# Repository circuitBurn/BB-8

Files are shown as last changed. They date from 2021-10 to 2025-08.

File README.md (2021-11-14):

## PCB files and Arduino sketches for FrSky SBUS control of Joe's Drive

### Required Libraries
* https://www.arduino.cc/reference/en/libraries/dfrobotdfplayermini/
* https://www.arduino.cc/reference/en/libraries/bolder-flight-systems-sbus/
* https://www.arduino.cc/reference/en/libraries/adafruit-bno055/
* https://github.com/adafruit/Adafruit-PWM-Servo-Driver-Library
* https://www.arduino.cc/reference/en/libraries/bts7960/

### TODO
* Calibration functions
* General cleanup

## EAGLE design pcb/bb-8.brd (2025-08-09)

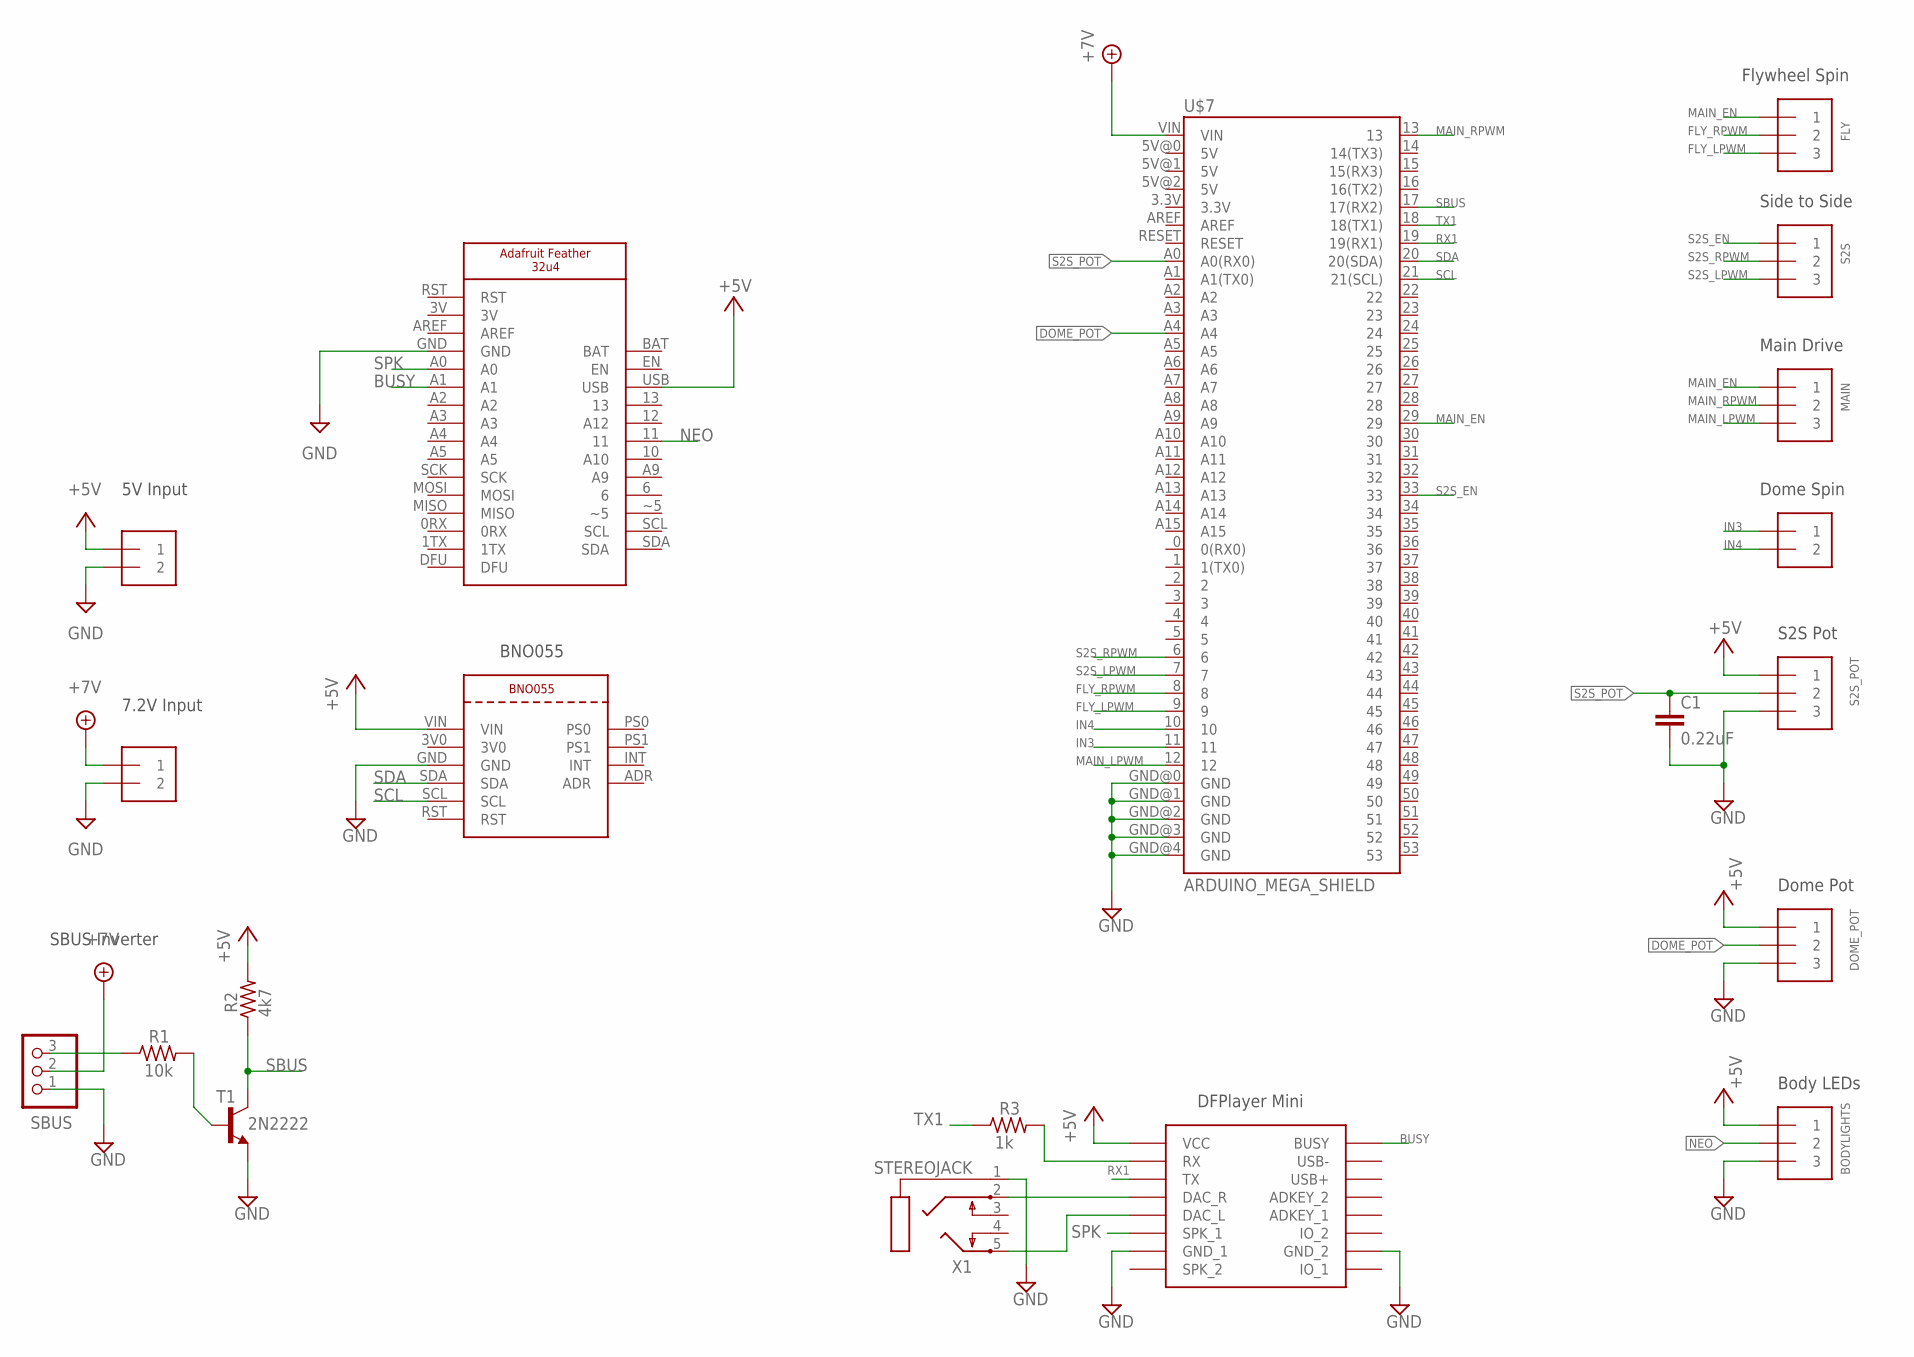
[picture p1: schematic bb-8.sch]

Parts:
5V, 7V2: 1X2-3.5MM
BODYLIGHTS: SCREW_TERMINAL_3_PIN
C1: 0.22uF; C050-024X044
DOME: 1X2-3.5MM
DOME_POT: SCREW_TERMINAL_3_PIN
FLY: SCREW_TERMINAL_3_PIN
MAIN: SCREW_TERMINAL_3_PIN
R1: 10k; 0204/7
R2: 4k7; 0204/7
R3: 1k; 0204/7
S2S, S2S_POT: SCREW_TERMINAL_3_PIN
SBUS: PINHD-1X3; 1X03
T1: 2N2222; TO92-EBC-OVAL
U$1: DFPLAYER
U$2: ADAFRUIT_BNO055
U$3: ADAFRUIT_FEATHER_32U4
U$7: ARDUINO_MEGA_SHIELD
X1: STEREOJACK; STX3100

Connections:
+5V: 5V.1, BODYLIGHTS.1, DOME_POT.1, R2.2, S2S_POT.1, U$1.VCC, U$2.VIN, U$3.USB
+7V: 7V2.1, SBUS.2, U$7.VIN
BUSY: U$1.BUSY, U$3.A1
DAC_R: U$1.DAC_R, X1.2
DOME_POT: DOME_POT.2, U$7.A4
FLY_LPWM: FLY.3, U$7.9
FLY_RPWM: FLY.2, U$7.8
GND: 5V.2, 7V2.2, BODYLIGHTS.3, C1.2, DOME_POT.3, S2S_POT.3, SBUS.1, T1.E, U$1.GND_1, U$1.GND_2, U$2.GND, U$3.GND, U$7.GND@0 (GND), U$7.GND@1 (GND), U$7.GND@2 (GND), U$7.GND@3 (GND), U$7.GND@4 (GND), X1.1
IN3: DOME.1, U$7.11
IN4: DOME.2, U$7.10
MAIN_EN: FLY.1, MAIN.1, U$7.29
MAIN_LPWM: MAIN.3, U$7.12
MAIN_RPWM: MAIN.2, U$7.13
unnamed: R1.2, T1.B
unnamed: R3.2, U$1.RX
unnamed: R1.1, SBUS.3
unnamed: U$1.DAC_L, X1.5
NEO: BODYLIGHTS.2, U$3.11
RX1: U$1.TX, U$7.19 (19(RX1))
S2S_EN: S2S.1, U$7.33
S2S_LPWM: S2S.3, U$7.7
S2S_POT: C1.1, S2S_POT.2, U$7.A0 (A0(RX0))
S2S_RPWM: S2S.2, U$7.6
SBUS: R2.1, T1.C, U$7.17 (17(RX2))
SCL: U$2.SCL, U$7.21 (21(SCL))
SDA: U$2.SDA, U$7.20 (20(SDA))
SPK: U$1.SPK1 (SPK_1), U$3.A0
TX1: R3.1, U$7.18 (18(TX1))

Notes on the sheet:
5V Input
7.2V Input
DFPlayer Mini
S2S Pot
Dome Pot
Flywheel Spin
Side to Side
Main Drive
Dome Spin
SBUS Inverter
BNO055
Body LEDs

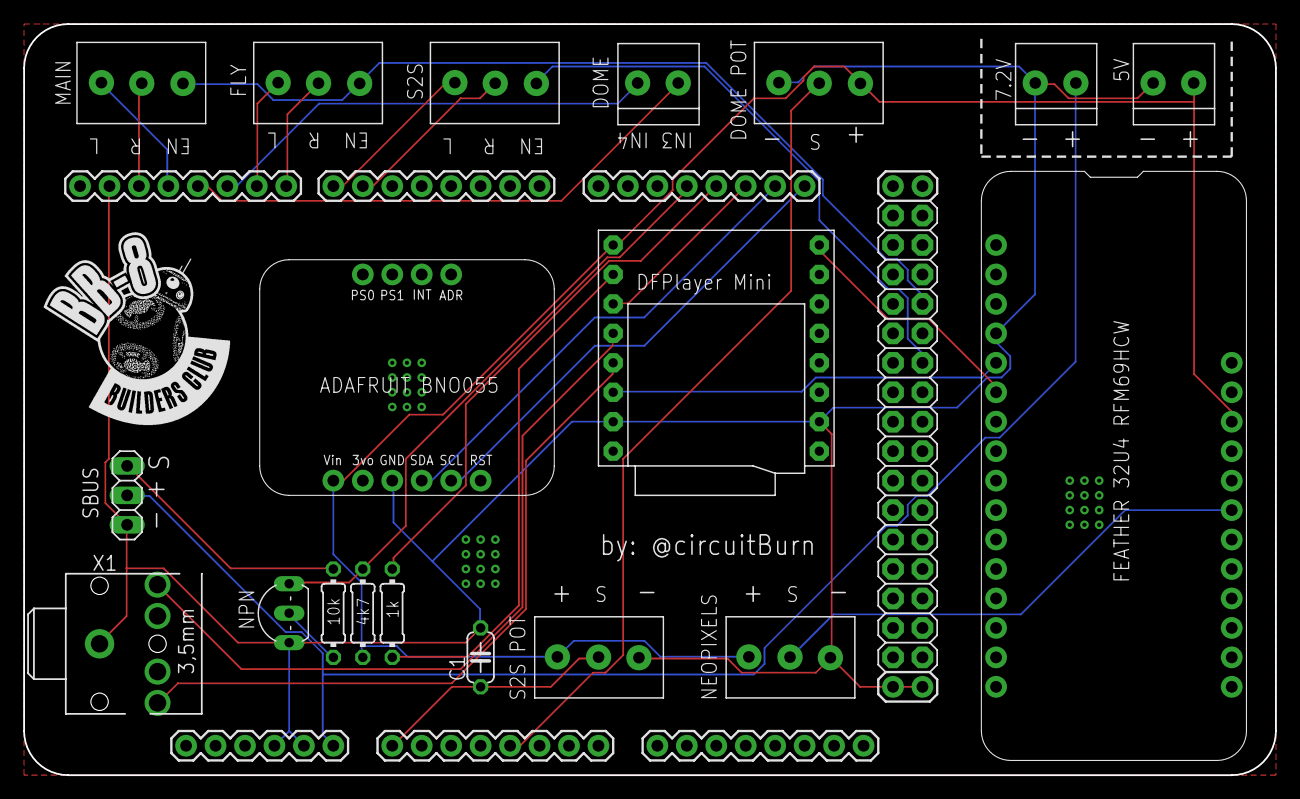
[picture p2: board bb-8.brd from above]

Board: 2 copper layers, 108.0 x 64.8 mm, 20 parts (0 on the bottom side), 28 nets.

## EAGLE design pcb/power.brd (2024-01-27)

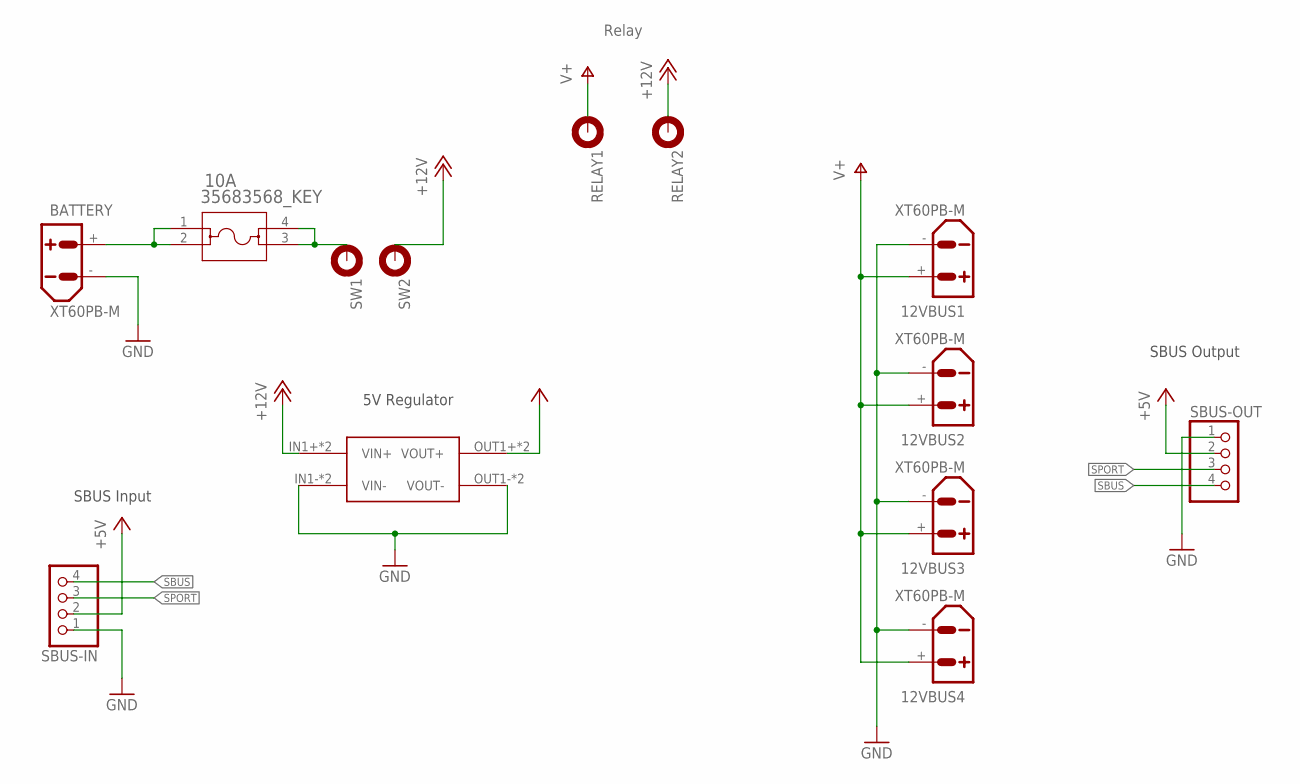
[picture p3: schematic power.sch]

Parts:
10A: 35683568_KEY; 3568_KEY
12VBUS1, 12VBUS2, 12VBUS3, 12VBUS4: XT60PB-M
BATTERY: XT60PB-M
RELAY1, RELAY2: MOUNT-PAD-ROUND2.8; 2,8-PAD
SBUS-IN: PINHD-1X4; 1X04
SBUS-OUT: PINHD-1X4; 1X04
SW1, SW2: MOUNT-PAD-ROUND2.8; 2,8-PAD
U$2: MP1584; DC-BRICK

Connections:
+5V: SBUS-IN.2, SBUS-OUT.2, U$2.OUT1+ (VOUT+), U$2.OUT2+ (VOUT+)
+12V: RELAY2.B2,8, SW2.B2,8, U$2.IN1+ (VIN+), U$2.IN2+ (VIN+)
GND: 12VBUS1.-, 12VBUS2.-, 12VBUS3.-, 12VBUS4.-, BATTERY.-, SBUS-IN.1, SBUS-OUT.1, U$2.IN1- (VIN-), U$2.IN2- (VIN-), U$2.OUT1- (VOUT-), U$2.OUT2- (VOUT-)
unnamed: 10A.1, 10A.2, BATTERY.+
unnamed: 10A.3, 10A.4, SW1.B2,8
SBUS: SBUS-IN.4, SBUS-OUT.4
SPORT: SBUS-IN.3, SBUS-OUT.3
V+: 12VBUS1.+, 12VBUS2.+, 12VBUS3.+, 12VBUS4.+, RELAY1.B2,8

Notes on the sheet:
SBUS Output
5V Regulator
SBUS Input
Relay

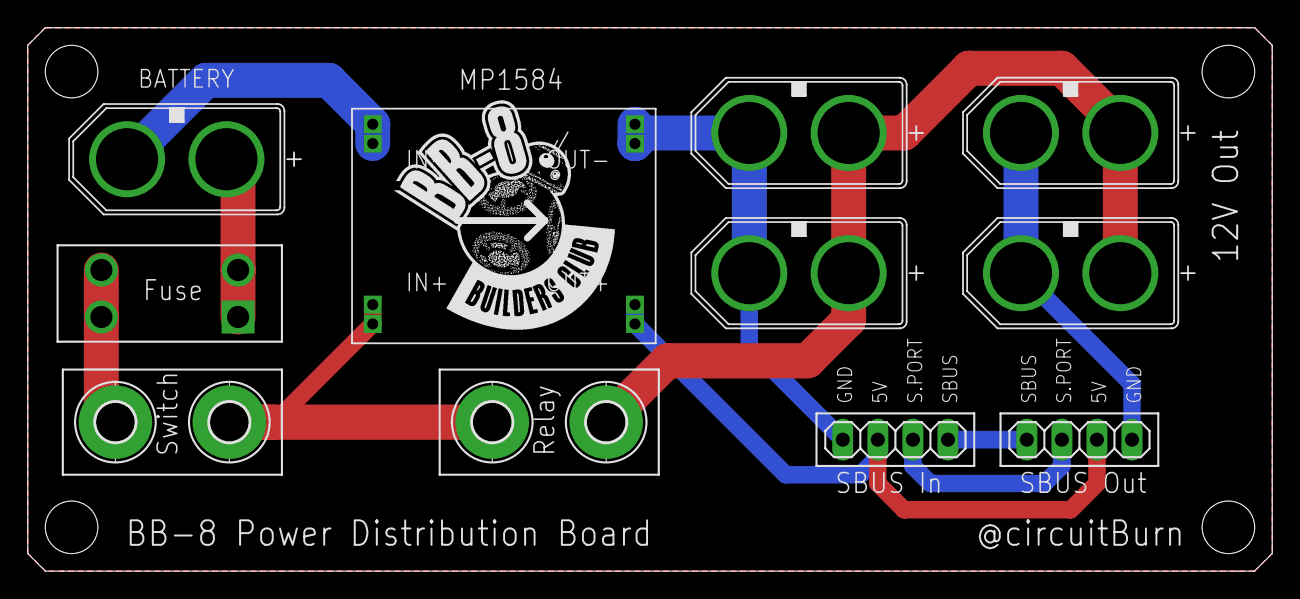
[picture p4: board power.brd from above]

Board: 2 copper layers, 90.2 x 39.4 mm, 13 parts (0 on the bottom side), 8 nets.

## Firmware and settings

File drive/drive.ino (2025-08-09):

/**
   FrSky SBUs RC control board for Joe's Drive Mk3

   Author:
      Patrick Ryan
      pat.m.ryan@gmail.com
      @circuitBurn

   Pin Mapping:
      See "constants.h"

   Serial Ports:
      Serial1 - DFPlayer Mini
      Serial2 - SBUS RC

   I2C:
      PWM Servo Board

   Resources:
      https://github.com/circuitBurn/BB-8
      https://bb8builders.club/
      https://www.facebook.com/groups/863379917081398
*/
#include "Arduino.h"
#include "sbus.h"
#include "DFRobotDFPlayerMini.h"
#include "BTS7960.h"
#include <PID_v1.h>
#include <Adafruit_Sensor.h>
#include <Adafruit_BNO055.h>
#include <Wire.h>
#include "constants.h"
#include "enums.h"

// PID1 is for the side to side tilt
double Pk1 = 24;
double Ik1 = 0;
double Dk1 = 0;
double Setpoint1, Input1, Output1, Output1a;
PID PID1(&Input1, &Output1, &Setpoint1, Pk1, Ik1, Dk1, DIRECT);

// PID2 for S2S stability
double Pk2 = 1.0;
double Ik2 = 0.0;
double Dk2 = 0.0;
double Setpoint2, Input2, Output2, Output2a;
PID PID2(&Input2, &Output2, &Setpoint2, Pk2, Ik2, Dk2, DIRECT);

// PID3 for the main drive
double Pk3 = 1.5;
double Ik3 = 0.0;
double Dk3 = 0.01;
double Setpoint3, Input3, Output3, Output3a;
PID PID3(&Input3, &Output3, &Setpoint3, Pk3, Ik3, Dk3, DIRECT);

// PID4 for dome rotation
double Pk4 = 2.0;
double Ik4 = 0.1;
double Dk4 = 0.01;
double Setpoint4, Input4, Output4;
PID PID4(&Input4, &Output4, &Setpoint4, Pk4, Ik4, Dk4, DIRECT);

// SBUS
bfs::SbusRx sbus_rx(&Serial2);

// Sound
DFRobotDFPlayerMini myDFPlayer;

// BTS7960 Motor Drivers
BTS7960 driveController(DRIVE_EN_PIN, DRIVE_L_PWM_PIN, DRIVE_R_PWM_PIN);
BTS7960 s2sController(S2S_EN_PIN, S2S_L_PWM_PIN, S2S_R_PWM_PIN);
BTS7960 flywheelController(DRIVE_EN_PIN, FLYWHEEL_L_PWM_PIN, FLYWHEEL_R_PWM_PIN);

// IMU
Adafruit_BNO055 bno = Adafruit_BNO055(-1, 0x28);
float pitch, roll;

// Drive mode
DriveMode driveMode = DriveMode::Disabled;

// Specifies the direction of BB-8
DriveDirection driveDirection = DriveDirection::Forward;

void setup()
{
  sbus_rx.Begin();

  randomSeed(analogRead(0));

  pinMode(DRIVE_R_PWM_PIN, OUTPUT);
  pinMode(DRIVE_L_PWM_PIN, OUTPUT);
  pinMode(DRIVE_EN_PIN, OUTPUT);

  pinMode(S2S_R_PWM_PIN, OUTPUT);
  pinMode(S2S_L_PWM_PIN, OUTPUT);
  pinMode(S2S_EN_PIN, OUTPUT);

  pinMode(FLYWHEEL_R_PWM_PIN, OUTPUT);
  pinMode(FLYWHEEL_L_PWM_PIN, OUTPUT);

  pinMode(DOME_SPIN_A_PIN, OUTPUT);
  pinMode(DOME_SPIN_B_PIN, OUTPUT);

  // Motor Drivers
  driveController.Enable();
  s2sController.Enable();
  flywheelController.Enable();

  // PID Setup - S2S servo
  PID1.SetMode(AUTOMATIC);
  PID1.SetOutputLimits(-255, 255);
  PID1.SetSampleTime(15);

  // PID Setup - S2S stability
  PID2.SetMode(AUTOMATIC);
  PID2.SetOutputLimits(-255, 255);
  PID2.SetSampleTime(15);

  // PID Setup - main drive motor
  PID3.SetMode(AUTOMATIC);
  PID3.SetOutputLimits(-255, 255);
  PID3.SetSampleTime(15);

  // PID Setup - dome motor
  PID4.SetMode(AUTOMATIC);
  PID4.SetOutputLimits(-255, 255);
  PID4.SetSampleTime(15);

  /* Initialise the IMU */
  if (!bno.begin())
  {
    while (1)
      ;
  }

  // Sound
  Serial1.begin(9600);
  myDFPlayer.begin(Serial1);
  myDFPlayer.volume(30);
  myDFPlayer.play(1);
}

void loop()
{
  readIMU();

  if (sbus_rx.Read())
  {
    driveMode = getDriveMode();
    driveDirection = getDriveDirection();

    if (driveMode == DriveMode::Enabled)
    {
      enableDrive();
      mainDrive();
      flywheel();
      sideToSide();
      domeSpin();
      checkAudioTrigger();
    }
    else if (driveMode == DriveMode::Static)
    {
      disableDrive();
      domeSpin();
      checkAudioTrigger();
    }
    else
    {
      // Disabled
      disableDrive();
    }
  }
}

/**
   ReadIMU

   Leaning forward = +y
   Tilting left    = -z

   Pitch is leaning forwards/backwards - Y axis
   Roll is leaning sideways - Z axis
*/
void readIMU()
{
  imu::Vector<3> euler = bno.getVector(Adafruit_BNO055::VECTOR_EULER);
  pitch = euler.y();
  roll = euler.z();
}

bool inRcDeadband(int value)
{
  return value >= RC_DEADBAND_LOW && value <= RC_DEADBAND_HIGH;
}

float mapFloat(long x, long in_min, long in_max, long out_min, long out_max)
{
  return (float)(x - in_min) * (out_max - out_min) / (float)(in_max - in_min) + out_min;
}

/**
 * @returns DriveMode
 */
DriveMode getDriveMode()
{
  int driveVal = sbus_rx.data().ch[CH_DRIVE_EN];
  if (driveVal == RC_MIN)
  {
    return DriveMode::Enabled;
  }
  else if (driveVal == RC_MID)
  {
    return DriveMode::Static;
  }
  else
  {
    return DriveMode::Disabled;
  }
}

/**
 * Drive can be "reversed" to make a quick turnaround
 */
DriveDirection getDriveDirection()
{
  int val = sbus_rx.data().ch[CH_DIRECTION];
  if (val < RC_MAX)
  {
    return DriveDirection::Forward;
  }
  else
  {
    return DriveDirection::Reverse;
  }
}

void disableDrive()
{
  flywheelController.Disable();
  s2sController.Disable();
  driveController.Disable();
}

void enableDrive()
{
  flywheelController.Enable();
  s2sController.Enable();
  driveController.Enable();
}

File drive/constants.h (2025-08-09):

/*****************************************************************************/
// RC Values
// - These are defined by the limits of your transmitter
/*****************************************************************************/
#define RC_MIN 172
#define RC_MID 992
#define RC_MAX 1811

/*****************************************************************************/
// RC Deadband
// - Set a range of values to be considered "off"
// - Anything in between these values is "off"
/*****************************************************************************/
#define RC_DEADBAND_LOW 962
#define RC_DEADBAND_HIGH 978

/*****************************************************************************/
// RC Channel Mapping
// - The channels are N - 1 where N is the defined channel number on the transmitter
// - Ex: CH1 on Tx is 0 here, CH2 is 1
/*****************************************************************************/
#define CH_DRIVE_MAIN 0
// 1: Channel 2 is directly connected to dome servo
// 2: Channel 3 is directly connected to dome servo 
#define CH_DRIVE_S2S 3
#define CH_FLYWHEEL 4
#define CH_DOME_SPIN 5
// 6: Channel 7 is the RC relay
#define CH_SOUND_TRIGGER 7
#define CH_SOUND_BANK 8
#define CH_DRIVE_EN 9
#define CH_DIRECTION 10
#define CH_ROLL_OFFSET 11
#define CH_FLYWHEEL_EN 12
#define CH_S2S_OFFSET 13
#define CH_RANDOM_SOUND 14

/*****************************************************************************/
// Main drive motor controller
/*****************************************************************************/
#define DRIVE_R_PWM_PIN 13
#define DRIVE_L_PWM_PIN 12
#define DRIVE_EN_PIN 29
#define MAX_DRIVE_SPEED 125 // 0 - 255

/*****************************************************************************/
// Flywheel motor controller
/*****************************************************************************/
#define FLYWHEEL_R_PWM_PIN 8
#define FLYWHEEL_L_PWM_PIN 9

/*****************************************************************************/
// Side to side motor controller
/*****************************************************************************/
#define S2S_R_PWM_PIN 6
#define S2S_L_PWM_PIN 7
#define S2S_EN_PIN 33
#define S2S_POT_PIN A0
#define S2S_MAX_ANGLE 40
#define S2S_EASING 0.9
#define S2S_OFFSET 0 // Negative value here will tilt the drive to the right

/*****************************************************************************/
// Dome servos and spin motor
/*****************************************************************************/
#define DOME_SPIN_A_PIN 10
#define DOME_SPIN_B_PIN 11
#define DOME_POT_PIN A4
#define DOME_SPIN_SPEED 125 // 0 - 255 for spinning completely around
#define DOME_TURN_SPEED 100 // 0 - 255 for looking around
#define DOME_POT_OFFSET 20

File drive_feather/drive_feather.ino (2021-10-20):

#include <Adafruit_NeoPixel.h>
#include <SPI.h>
#include <RH_RF69.h>

#include "Commands.h"

#define BUSY_SPK A0
#define BUSY_PIN A1

#define NEOPIXEL_PIN 11
#define NEOPIXEL_COUNT 20
#define RF69_FREQ 915.0

#define RFM69_CS 8
#define RFM69_INT 7
#define RFM69_RST 4

#define LED_PIN 11
#define LED_COUNT 6
#define BRIGHTNESS 255

// Individual LED addresses
#define LED_HP 0
#define LED_PSI 1
#define FRONT_LOGIC_1 2
#define FRONT_LOGIC_2 3
#define REAR_LOGIC_1 4
#define REAR_LOGIC_2 5

// Singleton instance of the radio driver
RH_RF69 rf69(RFM69_CS, RFM69_INT);


Adafruit_NeoPixel body = Adafruit_NeoPixel(NEOPIXEL_COUNT, NEOPIXEL_PIN, NEO_GRB + NEO_KHZ800);

unsigned long panel1Millis;
int panel1State = 1;
int r1 = 0;
int b1 = 0;

unsigned long panel2Millis;
int panel2State = 1;
int b21;
int b22;
int b23;
int b24;

unsigned long panel3Millis;
int panel3State = 1;
int r31 = 255;
int b31;
int r32;
int b32 = 255;

unsigned long panel4Millis;
int r41;
int b41 = 255;
int r42 = 255;
int b42;

int b5State = 1;
int b5;

int panel6State = 1;
int r61 = 0;
int b61 = 255;
int r62 = 255;
int b62 = 0;

unsigned long lastMillis;

//int16_t packetnum = 0;  // packet counter, we increment per xmission

void setup()
{
  //  Serial.begin(115200);
  pinMode(RFM69_RST, OUTPUT);
  digitalWrite(RFM69_RST, LOW);

  // manual reset
  digitalWrite(RFM69_RST, HIGH);
  delay(10);
  digitalWrite(RFM69_RST, LOW);
  delay(10);

  if (!rf69.init())
  {
    while (1)
      ;
  }

  // Defaults after init are 434.0MHz, modulation GFSK_Rb250Fd250, +13dbM (for low power module)
  // No encryption
  if (!rf69.setFrequency(RF69_FREQ))
  {
    while (1)
      ;
  }

  // If you are using a high power RF69 eg RFM69HW, you *must* set a Tx power with the
  // ishighpowermodule flag set like this:
  rf69.setTxPower(20, true); // range from 14-20 for power, 2nd arg must be true for 69HCW

  // The encryption key has to be the same as the one in the server
  //  uint8_t key[] = {0x01, 0x02, 0x03, 0x04, 0x05, 0x06, 0x07, 0x08,
  //                   0x01, 0x02, 0x03, 0x04, 0x05, 0x06, 0x07, 0x08
  //                  };

  uint8_t key[] = {0x03, 0x01, 0x08, 0x06, 0x07, 0x01, 0x05, 0x05,
                   0x03, 0x01, 0x08, 0x06, 0x07, 0x01, 0x05, 0x05
                  };

  rf69.setEncryptionKey(key);

  body.begin();
  body.show();

  turnPSIOff();
}

void loop()
{
  if ((millis() - lastMillis) > 50)
  {
    panel1();
    panel2();
    panel3();
    panel4();
    panel5();
    panel6();

    body.show();

    lastMillis = millis();
  }

  // Speaker light
  int sound = analogRead(A0);
  if (sound > 800)
  {
    turnPSIOn();
  }
  else if (sound < 790)
  {
    turnPSIOff();
  }
  else
  {
    turnPSIOff();
  }
}

void turnPSIOn()
{
  uint8_t data[] = "O";
  rf69.send((uint8_t *)data, strlen(data));
}

void turnPSIOff()
{
  uint8_t data[] = "F";
  rf69.send((uint8_t *)data, strlen(data));
}

void panel1()
{
  if (panel1State == 1 && b1 <= 255)
  {
    r1 ++;
    b1 += 8;

    if (b1 >= 240) {
      panel1State = 2;
      panel1Millis = millis();
    }

  } else if (panel1State == 2 && (millis() - panel1Millis >= 4500)) {

    r1 --;
    b1 -= 8;

    if (b1 <= 20 || r1 <= 1) {
      panel1State = 1;
    }

  }
  constrain(r1, 0, 30);
  constrain(b1, 0, 255);

  body.setPixelColor(0, body.Color(r1, 0, b1));
  body.setPixelColor(1, body.Color(r1, 0, b1));

}


void panel2() {

  if (panel2State == 1) {
    if (b21 <= 250) {
      b21 += 5;
      constrain(b21, 0, 255);
    }

    if (b21 >= 80 && b22 <= 250) {
      b22 += 5;
      constrain(b22, 0, 255);
    }

    if (b22 >= 80 && b23 <= 250) {
      b23 += 5;
      constrain(b23, 0, 255);
    }

    if (b23 >= 80 && b24 <= 250) {
      b24 += 5;
      constrain(b24, 0, 255);
      if (b24 >= 245) {

        panel2Millis = millis();
        panel2State = 2;
      }
    }
  } else if (millis() - panel2Millis >= 6000) {
    if (b21 >= 5) {
      b21 -= 5;
      constrain(b21, 0, 255);
    }

    if (b21 <= 180 && b22 >= 5) {
      b22 -= 5;
      constrain(b22, 0, 255);
    }

    if (b22 <= 180 && b23 >= 5) {
      b23 -= 5;
      constrain(b23, 0, 255);
    }

    if (b23 <= 180 && b24 >= 5) {
      b24 -= 5;
      constrain(b24, 0, 255);
    } else if (b24 <= 5) {
      panel2State = 1;
    }
  }



  body.setPixelColor(2, body.Color(0, 0, b21));
  body.setPixelColor(3, body.Color(0, 0, b22));
  body.setPixelColor(4, body.Color(0, 0, b23));
  body.setPixelColor(5, body.Color(0, 0, b24));


}




void panel3() {

  if (panel3State == 1 && (millis() - panel3Millis >= 7500)) {
    r31 -= 15;
    b31 += 15;
    r32 += 15;
    b32 -= 15;

    if (b31 == 255) {
      panel3Millis = millis();
      panel3State = 2;
    }
  } else if (panel3State == 2 && (millis() - panel3Millis >= 3750)) {
    r32 -= 15;
    b32 += 15;
    r31 += 15;
    b31 -= 15;

    if (b31 == 0) {
      panel3Millis = millis();
      panel3State = 1;
    }
  }



  constrain(r31, 0, 255);
  constrain(r32, 0, 255);
  constrain(b31, 0, 255);
  constrain(b32, 0, 255);

  body.setPixelColor(10, body.Color(r31, 0, b31));
  body.setPixelColor(7, body.Color(r31, 0, b31));
  body.setPixelColor(8, body.Color(r31, 0, b31));
  body.setPixelColor(9, body.Color(r31, 0, b31));
  body.setPixelColor(6, body.Color(r32, 0, b32));


}




void panel4() {

  if (millis() - panel4Millis >= 10000) {

    if (r41 == 155) {
      r41 = 0;
      b41 = 155;
      r42 = 155;
      b42 = 0;
      panel4Millis = millis();
    } else if (r41 == 0) {
      r41 = 155;
      b41 = 0;
      r42 = 0;
      b42 = 155;
      panel4Millis = millis();

    }

  }

  body.setPixelColor(11, body.Color(r41, 0, b41));
  body.setPixelColor(12, body.Color(r42, 0, b42));
  body.setPixelColor(13, body.Color(r41, 0, b41));
  body.setPixelColor(14, body.Color(100, 100, 100));
  body.setPixelColor(15, body.Color(r42, 0, b42));
  body.setPixelColor(16, body.Color(r42, 0, b42));
}


void panel5() {

  if (b5State == 1) {
    b5++;
    if (b5 >= 200) {
      b5State = 2;
    }
  } else if (b5State == 2) {
    b5--;
    if (b5 <= 20) {
      b5State = 1;
    }
  }
  body.setPixelColor(17, body.Color(0, 0, b5));


}

void panel6() {

  if (panel6State == 1) {

    r61 += 2;
    b61 -= 2;
    r62 -= 2;
    b62 += 2;

    constrain(r61, 0, 255);
    constrain(r62, 0, 255);
    constrain(b61, 0, 255);
    constrain(b62, 0, 255);

    body.setPixelColor(18, body.Color(r61, 0, b61));
    body.setPixelColor(19, body.Color(r62, 0, b62));

    if (r61 >= 250) {
      panel6State = 2;
    }

  } else if (panel6State == 2) {

    r62 += 2;
    b62 -= 2;
    r61 -= 2;
    b61 += 2;
    constrain(r61, 0, 255);
    constrain(r62, 0, 255);
    constrain(b61, 0, 255);
    constrain(b62, 0, 255);

    body.setPixelColor(18, body.Color(r61, 0, b61));
    body.setPixelColor(19, body.Color(r62, 0, b62));

    if (r62 >= 250) {
      panel6State = 1;
    }

  }

}

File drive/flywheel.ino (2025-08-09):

int flywheelRaw, flywheelSpeed;
bool flywheelEnabled = false;

/**
   The flywheel is mapped to the self-centering pot knob of a 3-axis joystick.
*/
void flywheel()
{
  flywheelRaw = sbus_rx.data().ch[CH_FLYWHEEL];
  flywheelRaw = constrain(flywheelRaw, RC_MIN, RC_MAX);
  flywheelSpeed = map(flywheelRaw, RC_MIN, RC_MAX, 255, -255);
  flywheelEnabled = sbus_rx.data().ch[CH_FLYWHEEL_EN] == RC_MAX;

  if (!flywheelEnabled || inRcDeadband(flywheelRaw))
  {
    flywheelController.Stop();
  }
  else
  {
    if (flywheelSpeed < 0)
    {
      flywheelController.TurnRight(abs(flywheelSpeed));
    }
    else
    {
      flywheelController.TurnLeft(flywheelSpeed);
    }
  }
}

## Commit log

2021-07-19 Adding EAGLE PCB schematic and board files
    [bb-8.brd, bb-8.sch]
2021-10-13 Fixing dome servo code
    [drive.ino, drive_feather.ino]
2021-11-14 Add bodge factor to S2S
    [drive.ino]
2021-12-21 Schematic updates
2022-08-20 Squashed commit of the following:
    commit c327650e5103bb6a6949c6a1538a163dea4dba5a
    Author: Patrick Ryan <pat.m.ryan@gmail.com>
    Date: Sat Aug 20 09:49:49 2022 -0400
    Updates to PCB
    commit 971e034c2edcb3dc5db781baa092387508605f21
    Author: Patrick Ryan <pat.m.ryan@gmail.com>
    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
    [bb-8.bak.brd, bb-8.brd, bb-8.dxf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]
2022-11-03 Adding quick reverse switch
    [constants.h, dome.ino, drive.ino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]
2024-01-27 Removing backup files
    [bb-8.bak.brd, bb-8.brd, bb-8.dxf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]
2024-01-27 Adding power board PCB and schematic
    [power.brd, power.sch]
2025-07-21 Updates to board
    [bb-8.brd, bb-8.sch]
2025-08-09 Updating PCB
    - Removing I2C lines
    - Fixing PCB power issues
    [bb-8.brd, bb-8.sch]

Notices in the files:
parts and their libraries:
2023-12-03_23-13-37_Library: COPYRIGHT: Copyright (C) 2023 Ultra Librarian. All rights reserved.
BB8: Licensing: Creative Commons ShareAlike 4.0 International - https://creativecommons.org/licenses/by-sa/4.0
